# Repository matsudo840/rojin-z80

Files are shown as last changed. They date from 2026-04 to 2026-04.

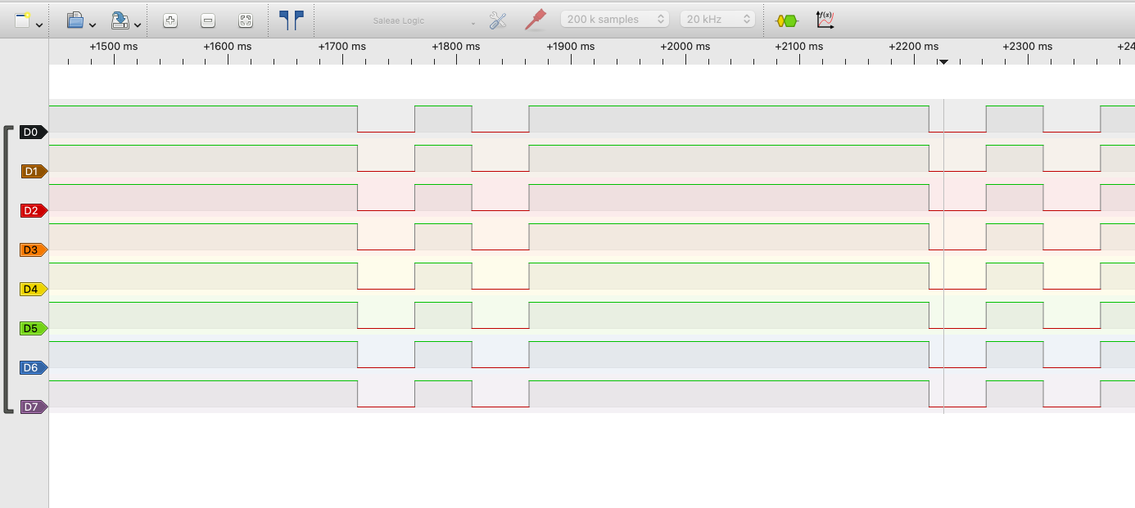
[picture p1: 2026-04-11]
images/step3_databus_waveform.png

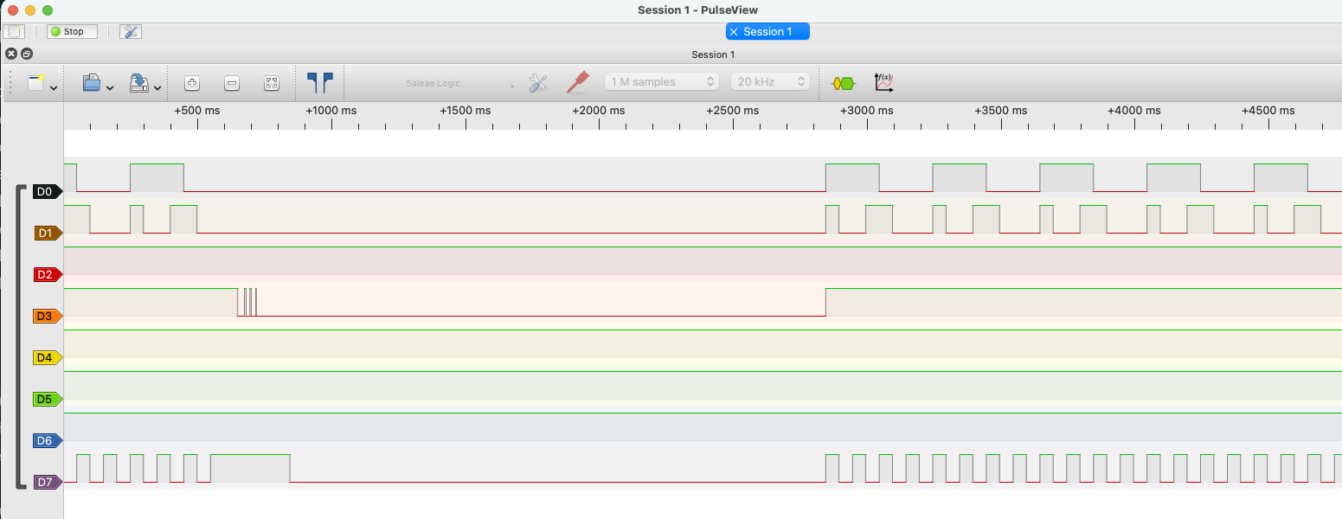
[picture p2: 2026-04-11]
images/z80_soft_reset_success.png

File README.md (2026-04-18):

# 老人Z80 - ESP32-S3によるZ80 CPU介護プロジェクト

このレポジトリは、[エムスリーテックブック9](https://techbookfest.org/product/tQtQhhFVHnRkH0bFCUikYK?productVariantID=5prWVthbVuZMdKxmcTBut0) 第9章「老人Z80 — ESP32によるZ80 CPU介護ボード製作記」のサポートページです。

本プロジェクトは、1970年代の名機Z80 CPUを、現代のパワフルなマイコン ESP32-S3 によって構築されたソフトウェア空間（仮想バス）上で動作させる、最新鋭の装置による旧来の存在の介護をテーマにした電子工作プロジェクトです。

## コンセプト
1991年のアニメ映画『老人Z』に登場する全自動看護ベッド「Z-001」から着想を得ました。
物理的なROMやRAM、周辺ICを一切排除し、ESP32-S3が「メモリ」「I/O」「クロック供給」「制御バスの調停」の役割をすべてソフトウェアで代行します。

- Z80から見た世界: 40年前と同じように周辺回路に囲まれている。
- 現実: ESP32-S3のソフトウェアが作り出す仮想バス空間上で、1サイクルごとに歩調を合わせられながら動作している。

## システム構成
- CPU: Zilog Z84C0008PEC (CMOS版 Z80)
- 介護マイコン: ESP32-S3 (ESP32-S3-DevKitC-1等)
- レベルシフタ: 74LVC245 (5V系Z80と3.3V系ESP32の電圧変換)
- 周辺機器: I2C 128x64 OLED (SSD1306)

### 介護（エミュレート）の内容
1. クロック供給: ESP32のGPIOから規則的なパルスを供給。
2. 仮想メモリ: ESP32のRAM上に確保した64KBの配列をZ80のメモリ空間として提供。
3. 同期制御: `/WAIT` 信号を用いて、ESP32側の処理（メモリ読み書きやOLED描画）が終わるまでZ80を一時停止。
4. I/Oブリッジ: Z80のI/Oリクエストを検知し、現代のI2C OLEDディスプレイへ文字出力。

## ディレクトリ構成
- `examples/`: 開発ステップごとのファームウェア・スナップショット。
- `firmware/`: ESP32-S3用のPlatformIOプロジェクト。
- `hardware/`: ピンアサイン、部品表(BOM)、回路図などのドキュメント。
- `images/`: 波形キャプチャや実行の様子。
- `tools/`: ロジックアナライザの波形（VCD形式）を解析するPythonスクリプト。

## 使い方
### ファームウェアの書き込み
`firmware/` ディレクトリをPlatformIO（VSCode拡張機能等）で開き、ESP32-S3に書き込みます。

### Z80アセンブラの実行
`firmware/src/main.cpp` 内の仮想メモリ配列に、Z80のアセンブラをバイナリ形式で配置することで実行可能です。

## 解析ツール
`tools/` 内のスクリプトを使用することで、ロジックアナライザで取得した波形データから、Z80がどのように命令をフェッチし、実行しているかを解析できます。

```bash
python tools/parse_vcd_fetch.py data.vcd
```

## ライセンス
MIT License

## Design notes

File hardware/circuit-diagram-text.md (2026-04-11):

# 老人Z80 回路図

## 1. システム全体ブロック図

```
┌─────────────────────────────────────────────────────────────┐
│                     電源供給系統                              │
├─────────────────────────────────────────────────────────────┤
│  USB 5V ──┬─→ Z80 (VCC)                                     │
│           ├─→ 74HC574 (VCC)                                 │
│           └─→ レベルシフタ A側 (5V入力)                      │
│                                                               │
│  ESP32 3.3V ─┬─→ レベルシフタ VCC (3.3V)                    │
│              └─→ レベルシフタ B側 (3.3V入力)                 │
│                                                               │
│  共通GND ────┴─ すべてのデバイスのGNDを接続                  │
└─────────────────────────────────────────────────────────────┘

┌──────────────┐
│   Z80 CPU    │  ← 老人（演算主体）
│  (5V駆動)    │
└──────────────┘
       │
       │ (神経接続: レベルシフタで電圧変換)
       │
       ↓
┌──────────────┐
│  LVC245 ×5   │  ← 神経系（5V ↔ 3.3V変換）
│ レベルシフタ  │
└──────────────┘
       │
       ↓
┌──────────────┐
│   ESP32-S3   │  ← 介護士（クロック供給、仮想メモリ、AI通信）
│  (3.3V駆動)  │
└──────────────┘
       │
       │ Wi-Fi
       ↓
   ChatGPT API
```

## 2. 詳細ピン接続図

### 2.1 アドレスバス (Z80 → ESP32) 一方向

```
┌─────────────┐          ┌─────────────┐          ┌─────────────┐
│   Z80       │          │  LVC245 #1  │          │  ESP32-S3   │
│             │          │  (Dir=Low)  │          │             │
│  A0  (pin30)├─────────→│ A1 → B1 ────┼─────────→│ GPIO 1      │
│  A1  (pin31)├─────────→│ A2 → B2 ────┼─────────→│ GPIO 2      │
│  A2  (pin32)├─────────→│ A3 → B3 ────┼─────────→│ GPIO 3      │
│  A3  (pin33)├─────────→│ A4 → B4 ────┼─────────→│ GPIO 4      │
│  A4  (pin34)├─────────→│ A5 → B5 ────┼─────────→│ GPIO 5      │
│  A5  (pin35)├─────────→│ A6 → B6 ────┼─────────→│ GPIO 6      │
│  A6  (pin36)├─────────→│ A7 → B7 ────┼─────────→│ GPIO 7      │
│  A7  (pin37)├─────────→│ A8 → B8 ────┼─────────→│ GPIO 8      │
└─────────────┘          └─────────────┘          └─────────────┘

┌─────────────┐          ┌─────────────┐          ┌─────────────┐
│   Z80       │          │  LVC245 #2  │          │  ESP32-S3   │
│             │          │  (Dir=Low)  │          │             │
│  A8  (pin38)├─────────→│ A1 → B1 ────┼─────────→│ GPIO 9      │
│  A9  (pin39)├─────────→│ A2 → B2 ────┼─────────→│ GPIO 10     │
│  A10 (pin40)├─────────→│ A3 → B3 ────┼─────────→│ GPIO 11     │
│  A11 (pin 1)├─────────→│ A4 → B4 ────┼─────────→│ GPIO 12     │
│  A12 (pin 2)├─────────→│ A5 → B5 ────┼─────────→│ GPIO 13     │
│  A13 (pin 3)├─────────→│ A6 → B6 ────┼─────────→│ GPIO 14     │
│  A14 (pin 4)├─────────→│ A7 → B7 ────┼─────────→│ GPIO 15     │
│  A15 (pin 5)├─────────→│ A8 → B8 ────┼─────────→│ GPIO 16     │
└─────────────┘          └─────────────┘          └─────────────┘
```

### 2.2 データバス (Z80 ↔ ESP32) 双方向

```
┌─────────────┐          ┌─────────────┐          ┌─────────────┐
│   Z80       │          │  LVC245 #3  │          │  ESP32-S3   │
│             │          │ (Dir制御)   │          │             │
│  D0  (pin14)├────────○─│ A1 ○ B1 ────┼────────○─│ GPIO 17     │
│  D1  (pin15)├────────○─│ A2 ○ B2 ────┼────────○─│ GPIO 18     │
│  D2  (pin12)├────────○─│ A3 ○ B3 ────┼────────○─│ GPIO 21     │
│  D3  (pin 8)├────────○─│ A4 ○ B4 ────┼────────○─│ GPIO 38     │
│  D4  (pin 7)├────────○─│ A5 ○ B5 ────┼────────○─│ GPIO 39     │
│  D5  (pin 9)├────────○─│ A6 ○ B6 ────┼────────○─│ GPIO 40     │
│  D6  (pin10)├────────○─│ A7 ○ B7 ────┼────────○─│ GPIO 41     │
│  D7  (pin13)├────────○─│ A8 ○ B8 ────┼────────○─│ GPIO 42     │
│             │          │             │          │             │
│             │          │ DIR (pin 1) │←─────────│ GPIO 19     │
└─────────────┘          └─────────────┘          └─────────────┘

※ GPIO 19 の制御:
  High: ESP32 → Z80 (データ書き込み)
  Low:  Z80 → ESP32 (データ読み込み)
```

### 2.3 制御信号

```
┌─────────────┐          ┌─────────────┐          ┌─────────────┐
│   Z80       │          │  LVC245 #4  │          │  ESP32-S3   │
│             │          │  (Dir制御)  │          │             │
│             │          │             │          │             │
│ CLK  (pin 6)│←─────────│ B1 ← A1 ────│←─────────│ GPIO 0      │
│WAIT (pin24) │←─────────│ B2 ← A2 ────│←─────────│ GPIO 45     │
│RESET(pin26) │←─────────│ B3 ← A3 ────│←─────────│ GPIO 46     │
│             │          │             │          │             │
└─────────────┘          └─────────────┘          └─────────────┘

┌─────────────┐          ┌─────────────┐          ┌─────────────┐
│   Z80       │          │  LVC245 #5  │          │  ESP32-S3   │
│             │          │  (Dir=Low)  │          │             │
│MREQ (pin19) ├─────────→│ A1 → B1 ────┼─────────→│ GPIO 47     │
│ RD  (pin21) ├─────────→│ A2 → B2 ────┼─────────→│ GPIO 48     │
└─────────────┘          └─────────────┘          └─────────────┘
```

### 2.4 出力系 (LED表示)

```
┌─────────────┐          ┌─────────────┐          ┌─────────────┐
│   Z80       │          │  74HC574    │          │   LED ×8    │
│             │          │  (ラッチ)   │          │             │
│  D0  (pin14)├─────────→│ D1 → Q1 ────┼─────────→│ LED 0       │
│  D1  (pin15)├─────────→│ D2 → Q2 ────┼─────────→│ LED 1       │
│  D2  (pin12)├─────────→│ D3 → Q3 ────┼─────────→│ LED 2       │
│  D3  (pin 8)├─────────→│ D4 → Q4 ────┼─────────→│ LED 3       │
│  D4  (pin 7)├─────────→│ D5 → Q5 ────┼─────────→│ LED 4       │
│  D5  (pin 9)├─────────→│ D6 → Q6 ────┼─────────→│ LED 5       │
│  D6  (pin10)├─────────→│ D7 → Q7 ────┼─────────→│ LED 6       │
│  D7  (pin13)├─────────→│ D8 → Q8 ────┼─────────→│ LED 7       │
│             │          │             │          │             │
│IORQ (pin20) ├──AND─────→│ CLK (pin11) │          │  (各LED直列に│
│  WR (pin22) ├──────┘    └─────────────┘          │   抵抗330Ω) │
└─────────────┘                                    └─────────────┘
```

## 3. 電源とGND配線

```
┌────────────────────────────────────────────────┐
│  5V系統 (USB)                                  │
├────────────────────────────────────────────────┤
│  ・Z80 VCC (pin 11)                            │
│  ・74HC574 VCC (pin 20)                        │
│  ・LVC245 #1～#5 A側入力 (5V)                  │
└────────────────────────────────────────────────┘

┌────────────────────────────────────────────────┐
│  3.3V系統 (ESP32から供給)                       │
├────────────────────────────────────────────────┤
│  ・LVC245 #1～#5 VCC (pin 20)                  │
│  ・LVC245 #1～#5 B側入力 (3.3V)                │
└────────────────────────────────────────────────┘

┌────────────────────────────────────────────────┐
│  共通GND                                        │
├────────────────────────────────────────────────┤
│  ・Z80 GND (pin 29)                            │
│  ・ESP32 GND (複数ピン)                         │
│  ・LVC245 #1～#5 GND (pin 10)                  │
│  ・74HC574 GND (pin 10)                        │
│  ・LED カソード (共通)                          │
│  ・USB GND                                     │
└────────────────────────────────────────────────┘
```

## 4. パスコン配置

```
各ICの電源ピン(VCC)とGND間に0.1μFセラミックコンデンサを配置:

・Z80: VCC(pin11) - GND(pin29)
・ESP32: 3V3ピン - GNDピン (複数箇所)
・LVC245 ×5: VCC(pin20) - GND(pin10) 各IC
・74HC574: VCC(pin20) - GND(pin10)
```

## 5. プルアップ抵抗配置

```
以下の信号線に10kΩプルアップ抵抗を5V電源に接続:

・Z80 データバス D0～D7 (8本)
・Z80 アドレスバス A0～A15 (16本)
・WAIT, RESET, MREQ, RD 信号
```

## 6. タイミングチャート（仮想メモリ読み出し）

```
CLK      ┐   ┌───┐   ┌───┐   ┌───
(GPIO 0) └───┘   └───┘   └───┘

MREQ     ────┐           ┌────────
(Z80→47)     └───────────┘

WAIT     ────┐       ┌────────────
(45→Z80)     └───────┘
             ↑       ↑
             │       └─ ESP32がデータ準備完了
             └───────── ESP32がZ80を停止

A0-A15   ────<アドレス確定>────────
(Z80→1-16)

D0-D7    ─────────<データ供給>────
(17-42)           ↑
                  └─ ESP32が仮想メモリから読み出したデータ

DIR      ────┐           ┌────────
(GPIO19)     └───────────┘
             High: ESP32→Z80
```

## 7. 部品配置の推奨レイアウト

```
[ブレッドボード 1枚目]
┌──────────────────────────┐
│   ESP32-S3 DevKit        │
│   (幅広: 40ピン程度)     │
└──────────────────────────┘

[ブレッドボード 2枚目]
┌──────────────────────────┐
│ LVC245 #1 (A0-A7)        │
│ LVC245 #2 (A8-A15)       │
│ LVC245 #3 (D0-D7)        │
└──────────────────────────┘

[ブレッドボード 3枚目]
┌──────────────────────────┐
│ Z80 CPU (DIPソケット)    │
│ LVC245 #4 (制御信号ESP→Z)│
│ LVC245 #5 (制御信号Z→ESP)│
│ 74HC574 + LED×8          │
└──────────────────────────┘
```

## 8. 配線色コーディング推奨

```
・5V電源: 赤
・3.3V電源: オレンジ
・GND: 黒
・アドレスバス: 黄色系
・データバス: 緑色系
・制御信号: 青色系
・クロック: 白
```

---

## 補足事項

### レベルシフタ方向制御
- LVC245 の DIR (pin 1) が High: A→B (5V→3.3V)
- LVC245 の DIR (pin 1) が Low: B→A (3.3V→5V)

### 注意点
1. すべてのレベルシフタのOE (pin 19) はGNDに接続（常時有効）
2. Z80のINT, NMI, BUSREQはプルアップして未使用
3. 74HC574のOE (pin 1) はGNDに接続（常時出力有効）

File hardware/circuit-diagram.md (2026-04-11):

# 老人Z80 回路図 (Mermaid版)

## 1. システム全体構成図

```mermaid
graph TB
    subgraph Power["電源供給系統"]
        USB[USB 5V電源]
        USB --> Z80_VCC[Z80 VCC]
        USB --> HC574_VCC[74HC574 VCC]
        USB --> LVC_A[レベルシフタ A側 5V]

        ESP_3V3[ESP32 3.3V出力]
        ESP_3V3 --> LVC_VCC[レベルシフタ VCC 3.3V]
        ESP_3V3 --> LVC_B[レベルシフタ B側 3.3V]

        GND[共通GND]
    end

    subgraph CPU["Z80 CPU (老人)"]
        Z80[Z84C0008<br/>8MHz CMOS<br/>5V駆動]
    end

    subgraph LevelShift["神経系 (電圧変換)"]
        LVC1[LVC245 #1<br/>A0-A7]
        LVC2[LVC245 #2<br/>A8-A15]
        LVC3[LVC245 #3<br/>D0-D7<br/>双方向]
        LVC4[LVC245 #4<br/>制御信号<br/>ESP→Z80]
        LVC5[LVC245 #5<br/>制御信号<br/>Z80→ESP]
    end

    subgraph MCU["ESP32 (介護士)"]
        ESP[ESP32-S3<br/>DevKitC-1<br/>N16R8<br/>3.3V駆動]
    end

    subgraph Output["出力系 (脈動)"]
        HC574[74HC574<br/>ラッチ]
        LED[LED×8<br/>バイタルサイン]
    end

    subgraph Cloud["AI (意識)"]
        ChatGPT[ChatGPT API<br/>プログラム生成]
    end

    Z80 -->|アドレスバス<br/>A0-A7| LVC1
    Z80 -->|アドレスバス<br/>A8-A15| LVC2
    Z80 <-->|データバス<br/>D0-D7| LVC3
    Z80 <-->|制御信号| LVC4
    Z80 -->|MREQ, RD| LVC5

    LVC1 -->|GPIO 1-8| ESP
    LVC2 -->|GPIO 9-16| ESP
    LVC3 <-->|GPIO 17-42| ESP
    LVC4 <-->|CLK(0), WAIT, RESET| ESP
    LVC5 -->|GPIO 47-48| ESP

    Z80 -->|データ出力| HC574
    HC574 --> LED

    ESP -->|Wi-Fi| ChatGPT

    style Z80 fill:#ff9999
    style ESP fill:#99ccff
    style LVC1 fill:#ffeb99
    style LVC2 fill:#ffeb99
    style LVC3 fill:#ffeb99
    style LVC4 fill:#ffeb99
    style LVC5 fill:#ffeb99
    style ChatGPT fill:#99ff99
```

## 2. データフロー詳細図

```mermaid
flowchart LR
    subgraph Z80_Side["Z80側 (5V)"]
        A_BUS[アドレスバス<br/>A0-A15<br/>16本]
        D_BUS[データバス<br/>D0-D7<br/>8本]
        CTRL_OUT[制御出力<br/>MREQ, RD]
        CTRL_IN[制御入力<br/>CLK, WAIT, RESET]
    end

    subgraph Converter["レベル変換 (5V ↔ 3.3V)"]
        LS_ADDR[LVC245 #1,#2<br/>Dir=Low<br/>一方向]
        LS_DATA[LVC245 #3<br/>Dir制御<br/>双方向]
        LS_OUT[LVC245 #5<br/>Dir=Low<br/>一方向]
        LS_IN[LVC245 #4<br/>Dir制御<br/>一方向]
    end

    subgraph ESP_Side["ESP32側 (3.3V)"]
        GPIO_ADDR[GPIO 1-16<br/>アドレス受信]
        GPIO_DATA[GPIO 17-42<br/>データ送受信]
        GPIO_MREQ[GPIO 47-48<br/>制御受信]
        GPIO_CTRL[GPIO 0,45,46<br/>制御送信]
        GPIO_DIR[GPIO 19<br/>方向制御]
    end

    A_BUS -->|5V| LS_ADDR
    LS_ADDR -->|3.3V| GPIO_ADDR

    D_BUS <-->|5V| LS_DATA
    LS_DATA <-->|3.3V| GPIO_DATA
    GPIO_DIR -.->|制御| LS_DATA

    CTRL_OUT -->|5V| LS_OUT
    LS_OUT -->|3.3V| GPIO_MREQ

    GPIO_CTRL -->|3.3V| LS_IN
    LS_IN -->|5V| CTRL_IN

    style A_BUS fill:#ffffcc
    style D_BUS fill:#ccffcc
    style CTRL_OUT fill:#ccccff
    style CTRL_IN fill:#ffccff
```

## 3. ピンアサイン詳細マップ

```mermaid
graph LR
    subgraph Z80_Pins["Z80 ピン配置"]
        direction TB
        A0_A7["A0-A7<br/>pin 30-37"]
        A8_A15["A8-A15<br/>pin 38-40, 1-5"]
        D0_D7["D0-D7<br/>pin 14,15,12,8,7,9,10,13"]
        CLK_PIN["CLK pin 6"]
        WAIT_PIN["WAIT pin 24"]
        RESET_PIN["RESET pin 26"]
        MREQ_PIN["MREQ pin 19"]
        RD_PIN["RD pin 21"]
    end

    subgraph LVC1_IC["LVC245 #1"]
        LVC1_A["A1-A8<br/>(5V側/Z80)"]
        LVC1_B["B1-B8<br/>(3.3V側/ESP)"]
        LVC1_A --> LVC1_B
    end

    subgraph LVC2_IC["LVC245 #2"]
        LVC2_A["A1-A8<br/>(5V側/Z80)"]
        LVC2_B["B1-B8<br/>(3.3V側/ESP)"]
        LVC2_A --> LVC2_B
    end

    subgraph LVC3_IC["LVC245 #3"]
        LVC3_A["A1-A8<br/>(5V側/Z80)"]
        LVC3_B["B1-B8<br/>(3.3V側/ESP)"]
        LVC3_DIR["DIR<br/>GPIO 19"]
        LVC3_B <--> LVC3_A
    end

    subgraph ESP_GPIO["ESP32 GPIO"]
        direction TB
        GPIO_1_8["GPIO 1-8"]
        GPIO_9_16["GPIO 9-16"]
        GPIO_17_42["GPIO 17,18,21,38-42"]
        GPIO_0["GPIO 0"]
        GPIO_45["GPIO 45"]
        GPIO_46["GPIO 46"]
        GPIO_47["GPIO 47"]
        GPIO_48["GPIO 48"]
        GPIO_19["GPIO 19"]
    end

    A0_A7 --> LVC1_A
    LVC1_B --> GPIO_1_8

    A8_A15 --> LVC2_A
    LVC2_B --> GPIO_9_16

    D0_D7 <--> LVC3_A
    LVC3_B <--> GPIO_17_42
    GPIO_19 --> LVC3_DIR

    GPIO_0 --> CLK_PIN
    GPIO_45 --> WAIT_PIN
    GPIO_46 --> RESET_PIN

    MREQ_PIN --> GPIO_47
    RD_PIN --> GPIO_48

    style A0_A7 fill:#ffe6cc
    style A8_A15 fill:#ffe6cc
    style D0_D7 fill:#ccffe6
    style CLK_PIN fill:#cce6ff
    style WAIT_PIN fill:#cce6ff
    style RESET_PIN fill:#cce6ff
```

## 4. 仮想メモリ動作シーケンス

```mermaid
sequenceDiagram
    participant Z80 as Z80 CPU
    participant CLK as CLK信号
    participant MREQ as MREQ信号
    participant WAIT as WAIT信号
    participant ESP as ESP32
    participant AI as ChatGPT

    Note over ESP,AI: 初期化: AIからプログラムを取得
    AI->>ESP: Z80マシン語コード送信
    ESP->>ESP: 仮想メモリに展開

    Note over Z80,ESP: 実行開始
    ESP->>CLK: クロックHigh
    activate Z80
    CLK->>Z80: 1クロック進行

    Z80->>MREQ: Low (メモリ要求)
    activate MREQ
    MREQ->>ESP: メモリアクセス検知

    ESP->>WAIT: Low (Z80を停止)
    activate WAIT
    WAIT->>Z80: 時間停止

    ESP->>ESP: アドレスバス読み取り<br/>(GPIO 1-16)
    ESP->>ESP: 仮想メモリから<br/>該当命令を取得

    ESP->>Z80: データバス経由で<br/>命令を供給<br/>(GPIO 17-42)

    ESP->>WAIT: High (停止解除)
    deactivate WAIT
    WAIT->>Z80: 時間再開

    deactivate MREQ
    Z80->>Z80: 命令実行
    deactivate Z80

    ESP->>CLK: クロックLow

    Note over Z80,ESP: 次のサイクルへ
```

## 5. タイミングチャート

```mermaid
%%{init: {'theme':'base'}}%%
gantt
    title Z80 仮想メモリ読み出しタイミング
    dateFormat X
    axisFormat %L

    section CLK (GPIO 0)
    High   :a1, 0, 100
    Low    :a2, 100, 100
    High   :a3, 200, 100

    section MREQ (Z80→47)
    High   :b1, 0, 50
    Low    :b2, 50, 150
    High   :b3, 200, 100

    section WAIT (45→Z80)
    High   :c1, 0, 60
    Low    :c2, 60, 100
    High   :c3, 160, 140

    section Address (Z80→1-16)
    Invalid:d1, 0, 50
    Valid  :crit, d2, 50, 150
    Invalid:d3, 200, 100

    section Data (17-42)
    HiZ    :e1, 0, 100
    Valid  :crit, e2, 100, 60
    HiZ    :e3, 160, 140

    section DIR (GPIO 19)
    Low    :f1, 0, 100
    High   :f2, 100, 60
    Low    :f3, 160, 140
```

## 6. 電源配線図

```mermaid
graph TD
    subgraph PowerSource["電源源"]
        USB[USB 5V]
        ESP_REG[ESP32 3.3V<br/>レギュレータ出力]
    end

    subgraph V5_Rail["5V電源レール"]
        Z80_V[Z80 VCC pin11]
        HC_V[74HC574 VCC pin20]
        LVC_A_V[LVC245 A側<br/>入力基準]
    end

    subgraph V3_Rail["3.3V電源レール"]
        LVC_VCC[LVC245 ×5<br/>VCC pin20]
        LVC_B_V[LVC245 B側<br/>入力基準]
    end

    subgraph GroundRail["共通GND"]
        Z80_G[Z80 GND pin29]
        ESP_G[ESP32 GND]
        LVC_G[LVC245 ×5<br/>GND pin10]
        HC_G[74HC574 GND pin10]
        LED_G[LED カソード]
        USB_G[USB GND]
    end

    subgraph Bypass["バイパスコンデンサ"]
        CAP_Z80[0.1μF<br/>Z80 VCC-GND]
        CAP_ESP[0.1μF ×複数<br/>ESP32]
        CAP_LVC[0.1μF ×5<br/>各LVC245]
        CAP_HC[0.1μF<br/>74HC574]
    end

    USB --> V5_Rail
    USB --> GroundRail
    ESP_REG --> V3_Rail
    ESP_REG --> GroundRail

    V5_Rail -.->|接続| CAP_Z80
    V5_Rail -.->|接続| CAP_HC
    V3_Rail -.->|接続| CAP_ESP
    V3_Rail -.->|接続| CAP_LVC

    CAP_Z80 -.-> GroundRail
    CAP_ESP -.-> GroundRail
    CAP_LVC -.-> GroundRail
    CAP_HC -.-> GroundRail

    style USB fill:#ff9999
    style ESP_REG fill:#99ccff
    style GroundRail fill:#333333,color:#ffffff
```

## 7. LED出力回路

```mermaid
graph LR
    subgraph Z80_Data["Z80 データバス"]
        D0[D0 pin14]
        D1[D1 pin15]
        D2[D2 pin12]
        D3[D3 pin8]
        D4[D4 pin7]
        D5[D5 pin9]
        D6[D6 pin10]
        D7[D7 pin13]
    end

    subgraph Control["制御信号"]
        IORQ[IORQ pin20]
        WR[WR pin22]
        AND[AND Gate]
        IORQ --> AND
        WR --> AND
    end

    subgraph Latch["74HC574 ラッチ"]
        direction TB
        IN[D1-D8入力]
        CLK_L[CLK pin11]
        OUT[Q1-Q8出力]
        IN --> OUT
    end

    subgraph LED_Array["LED表示"]
        LED0[LED0 + 330Ω]
        LED1[LED1 + 330Ω]
        LED2[LED2 + 330Ω]
        LED3[LED3 + 330Ω]
        LED4[LED4 + 330Ω]
        LED5[LED5 + 330Ω]
        LED6[LED6 + 330Ω]
        LED7[LED7 + 330Ω]
    end

    D0 --> IN
    D1 --> IN
    D2 --> IN
    D3 --> IN
    D4 --> IN
    D5 --> IN
    D6 --> IN
    D7 --> IN

    AND --> CLK_L

    OUT --> LED0
    OUT --> LED1
    OUT --> LED2
    OUT --> LED3
    OUT --> LED4
    OUT --> LED5
    OUT --> LED6
    OUT --> LED7

    LED0 --> GND[GND]
    LED1 --> GND
    LED2 --> GND
    LED3 --> GND
    LED4 --> GND
    LED5 --> GND
    LED6 --> GND
    LED7 --> GND

    style LED0 fill:#ffff99
    style LED1 fill:#ffff99
    style LED2 fill:#ffff99
    style LED3 fill:#ffff99
    style LED4 fill:#ffff99
    style LED5 fill:#ffff99
    style LED6 fill:#ffff99
    style LED7 fill:#ffff99
```

## 8. ブレッドボード配置図

```mermaid
graph TB
    subgraph BB1["ブレッドボード #1"]
        direction LR
        ESP32[ESP32-S3 DevKitC-1<br/>幅広40ピン構成<br/>両側に電源レール]
        POWER1[5V/3.3V/GND<br/>電源分配]
    end

    subgraph BB2["ブレッドボード #2"]
        direction LR
        LVC1[LVC245 #1<br/>A0-A7]
        LVC2[LVC245 #2<br/>A8-A15]
        LVC3[LVC245 #3<br/>D0-D7]
        LVC1 --- LVC2
        LVC2 --- LVC3
    end

    subgraph BB3["ブレッドボード #3"]
        direction LR
        Z80_IC[Z80 CPU<br/>DIP40ソケット]
        LVC4[LVC245 #4<br/>制御ESP→Z]
        LVC5[LVC245 #5<br/>制御Z→ESP]
        HC[74HC574<br/>+ LED×8]
        Z80_IC --- LVC4
        LVC4 --- LVC5
        LVC5 --- HC
    end

    BB1 -.->|フラットケーブル<br/>40本程度| BB2
    BB2 -.->|フラットケーブル<br/>20本程度| BB3

    style ESP32 fill:#99ccff
    style Z80_IC fill:#ff9999
    style LVC1 fill:#ffeb99
    style LVC2 fill:#ffeb99
    style LVC3 fill:#ffeb99
    style LVC4 fill:#ffeb99
    style LVC5 fill:#ffeb99
```

## 9. パスコン（バイパスコンデンサ）配置

各ICのVCC-GND間に0.1μFセラミックコンデンサを**できるだけ近く**に配置する。

| IC | 電源電圧 | パスコン容量 | 数量 | 配置位置 |
|----|---|---|---|---|
| Z80 CPU | 5V | 0.1μF | 1個 | pin11-pin29間 |
| 74HC574 | 5V | 0.1μF | 1個 | pin20-pin10間 |
| LVC245 #1 | 3.3V | 0.1μF | 1個 | pin20-pin10間 |
| LVC245 #2 | 3.3V | 0.1μF | 1個 | pin20-pin10間 |
| LVC245 #3 | 3.3V | 0.1μF | 1個 | pin20-pin10間 |
| LVC245 #4 | 3.3V | 0.1μF | 1個 | pin20-pin10間 |
| LVC245 #5 | 3.3V | 0.1μF | 1個 | pin20-pin10間 |
| ESP32-S3 | 3.3V | 0.1μF | 2-3個 | 各3.3V-GND間（複数箇所） |
| ESP32-S3 | 3.3V | 10μF | 1個 | 3.3V-GND間（バルク用） |

**合計必要数: 0.1μF × 9個、10μF × 1個**

## 10. 配線色コーディング

```mermaid
graph LR
    subgraph Colors["推奨配線色"]
        direction TB
        RED[赤: 5V電源]
        ORANGE[オレンジ: 3.3V電源]
        BLACK[黒: GND]
        YELLOW[黄色系: アドレスバス]
        GREEN[緑色系: データバス]
        BLUE[青色系: 制御信号]
        WHITE[白: クロック]
    end

    style RED fill:#ff0000,color:#ffffff
    style ORANGE fill:#ff9900,color:#000000
    style BLACK fill:#000000,color:#ffffff
    style YELLOW fill:#ffff00,color:#000000
    style GREEN fill:#00ff00,color:#000000
    style BLUE fill:#0099ff,color:#ffffff
    style WHITE fill:#ffffff,color:#000000
```

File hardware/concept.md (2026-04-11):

# 老人Z80 基本設計仕様書

## 1. コンセプト

1970年代の Z80 CPU を、ESP32-S3 と AI（ChatGPT）で包み込み、現代に蘇らせる「サイバー・レトロ」プロジェクト。

- **Z80 (Z84C0008)**: 本来は 5V 駆動だが、本プロジェクトでは 3.3V で駆動（しきい値ハック）。ESP32が提供する仮想メモリ上の命令を実行する。
- **ESP32-S3-DevKitC-1-N16R8**: 3.3V 駆動。Wi-Fi 経由で AI と通信し、Z80 用の仮想メモリとクロックを生成する。
- **レベルシフタ / バッファ (SN74LVC245AN)**: 当初は電圧変換 (5V ↔ 3.3V) を目的としていたが、現在は 3.3V 統一系における「バス・バッファ（保護およびドライブ能力向上）」として機能する。

---

## 2. ハードウェア構成

部品の詳細は [bom.md](bom.md) を参照。

---

## 3. 電源系統

### 5V系統
- **供給元**: USB電源
- **用途**:
  - Z80 (VCC pin 11)
  - 74HC574 (VCC pin 20)
  - レベルシフタのA側入力（5V基準）

### 3.3V系統
- **供給元**: ESP32の3.3V出力ピン
- **用途**:
  - レベルシフタ (VCC pin 20) - 全5個
  - レベルシフタのB側入力（3.3V基準）

### 共通GND
すべてのデバイスのGNDを一本化する。

---

## 4. ピンアサイン

> **重要**: 詳細なピン接続は [pin_map.md](pin_map.md) を正とします。

### 概要
- **アドレスバス (16本)**: GPIO 1～16
- **データバス (8本)**: GPIO 17, 18, 21, 38, 39, 40, 41, 42
- **制御信号**:
  - **CLK**: GPIO 0
  - **WAIT**: GPIO 45
  - **RESET**: GPIO 46
  - **MREQ**: GPIO 47
  - **RD**: GPIO 48
  - **DIR**: GPIO 19 (USB D-)

詳細なピン配置図は [circuit-diagram.md](circuit-diagram.md) を参照。

---

## 5. ソフトウェアロジック

### ① 仮想SRAMエミュレーション

1. ESP32が CLK をトグルし、Z80を1ステップ進める
2. Z80が MREQ をLowにしたら、ESP32は WAIT をLowにしてZ80を停止
3. ESP32がアドレスバスを読み取り、仮想メモリから該当する命令を取得
4. データバスに命令を出力し、WAIT を解除

### ② AI（ChatGPT）連携

1. Wi-Fi経由でOpenAI APIに接続
2. Z80用マシン語を生成させる
3. 受信したコードを仮想メモリに展開し、Z80に実行させる

### ③ デバッグ・モニタリング

- シリアル出力でバス状態を監視
- 実行トレースの記録
- リアルタイムでのメモリダンプ

---

## 6. 開発フェーズ

### Phase 1: 基本動作確認
- [ ] ブレッドボード配線
- [ ] 電源供給確認
- [ ] レベルシフタ動作確認
- [ ] クロック供給テスト
- [ ] LED点灯テスト

### Phase 2: 仮想メモリ実装
- [ ] ESP32でWAIT制御
- [ ] アドレスバス読み取り
- [ ] データバス書き込み
- [ ] 簡単なNOPループ実行
- [ ] 固定プログラムでのLチカ

### Phase 3: AI連携
- [ ] Wi-Fi接続
- [ ] ChatGPT API統合
- [ ] マシン語生成プロンプト最適化
- [ ] 自動実行パイプライン
- [ ] エラーハンドリング

### Phase 4: 拡張機能
- [ ] LED以外の出力デバイス
- [ ] 外部SRAM追加
- [ ] リアルタイムデバッガ
- [ ] Webインターフェース

---

## 7. 技術的課題

### 課題1: クロック速度のバランス
**問題**: ESP32の処理速度とZ80のクロック速度のバランス
**解決**: 可変クロック機能の実装。初期は低速（1kHz）から開始。

### 課題2: タイミング制約
**問題**: WAIT信号のタイミングが遅れるとZ80が誤動作
**解決**: GPIOの割り込みハンドラで最優先処理。アセンブリ最適化も検討。

### 課題3: メモリサイズ
**問題**: ESP32のメモリに64KBすべてを展開できない
**解決**: N16R8モデル（PSRAM 8MB）を使用。必要に応じてページング実装。

### 課題4: AI生成コードの検証
**問題**: ChatGPTが生成したマシン語が正しいとは限らない
**解決**: シミュレータでの事前検証機能を実装。

### 課題5: GPIOピンアサインの制約
詳細は [issues.md](issues.md) を参照。

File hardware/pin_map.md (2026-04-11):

# 老人Z80 GPIOピンアサイン定義書

このドキュメントは、本プロジェクトにおける ESP32-S3 と Z80 の接続ピン配置の **Single Source of Truth (唯一の正解)** です。
他のドキュメント (`concept.md`, `circuit-diagram.md`) と記述が食い違う場合は、**本書の記述を優先** します。

## 1. 方針と制約

1.  **USBポートの制限**: GPIOピン不足解消のため、`USB D-` (GPIO 19) を使用します。
    - **重要**: 開発および電源供給には **UARTポート** (USB-UARTブリッジ側) を使用してください。Native USBポートは使用できません。
2.  **RGB LED**: GPIO 48 (および一部のボードでは GPIO 38) は基板上の RGB LED (NeoPixel) に接続されています。これらは Z80 の制御信号（/RD 等）と競合するため、**起動時にソフトウェアで明示的に消灯** する必要があります。
3.  **Strapping Pins**: GPIO 0, 3, 45, 46 はブートモード決定ピンです。
    - ESP32の起動完了まで Z80 をリセット状態（ハイインピーダンス）に保つことで、ブート阻害を防ぎます。
14. **プルアップ構成**: 以下の信号線には、ノイズ対策およびフローティング防止のため、5Vへのプルアップ抵抗（例: $10 \text{k}\Omega$）を実装しています。
    - アドレスバス (A0-A15)
    - データバス (D0-D7)
    - 制御信号: INT, NMI, MREQ, IORQ, RD, WR, BUSACK, WAIT, BUSRQ, RESET, M1 (HALT, RFSHを除く主要信号)

## 2. ピンアサイン一覧

### A. アドレスバス (Z80 输出 → ESP32 入力)
| 信号名 | Z80 Pin | ESP32 GPIO | 備考 |
|:---|:---:|:---:|:---|
| **A0** | 30 | **GPIO 1** | |
| **A1** | 31 | **GPIO 2** | |
| **A2** | 32 | **GPIO 3** | Strap Pin (JTAG) |
| **A3** | 33 | **GPIO 4** | |
| **A4** | 34 | **GPIO 5** | |
| **A5** | 35 | **GPIO 6** | |
| **A6** | 36 | **GPIO 7** | |
| **A7** | 37 | **GPIO 8** | |
| **A8** | 38 | **GPIO 9** | |
| **A9** | 39 | **GPIO 10** | |
| **A10** | 40 | **GPIO 11** | |
| **A11** | 1 | **GPIO 12** | |
| **A12** | 2 | **GPIO 13** | |
| **A13** | 3 | **GPIO 0** | (← 14 から変更) Boot Button / Strap Pin |
| **A14** | 4 | **(N/C)** | GPIO不足のため廃止 |
| **A15** | 5 | **(N/C)** | GPIO不足のため廃止 |

### B. データバス (Z80 ⇔ ESP32 双方向)
| 信号名 | Z80 Pin | ESP32 GPIO | 備考 |
|:---|:---:|:---:|:---|
| **D0** | 14 | **GPIO 17** | |
| **D1** | 15 | **GPIO 18** | |
| **D2** | 12 | **GPIO 21** | |
| **D3** | 8 | **GPIO 38** | RGB LEDと競合の可能性あり |
| **D4** | 7 | **GPIO 39** | JTAG |
| **D5** | 9 | **GPIO 40** | JTAG |
| **D6** | 10 | **GPIO 41** | JTAG |
| **D7** | 13 | **GPIO 42** | JTAG |

### C. 制御信号
| 信号名 | 方向 | ESP32 GPIO | 役割・備考 |
|:---|:---:|:---:|:---|
| **CLK** | ESP→Z80 | **GPIO 14** | (← 0 から変更) コンデンサ回避のためクリーンなピンへ移動 |
| **WAIT** | ESP→Z80 | **GPIO 45** | Strap (Output) |
| **RESET** | ESP→Z80 | **GPIO 46** | Strap (Output) |
| **MREQ** | Z80→ESP | **GPIO 47** | Input |
| **RD** | Z80→ESP | **GPIO 48** | Input / **オンボードNeoPixelと共用 (要消灯)** |
| **WR** | Z80→ESP | **GPIO 16** | Input (A15から転用) |
| **IORQ** | Z80→ESP | **GPIO 35** | Input |
| **DIR** | ESP→LVC | **GPIO 15** | (A14から転用) |
| **SDA** | ESP⇔OLED | **GPIO 36** | I2C Data |
| **SCL** | ESP→OLED | **GPIO 37** | I2C Clock |

---

## 3. レベルシフタ (74LVC245) 構成

- **LVC #1**: A0-A7 (Direction: High 固定 / Z80→ESP)
- **LVC #2**: A8-A13 (Direction: High 固定 / Z80→ESP)
- **LVC #3**: D0-D7 (Direction: **GPIO 15** で制御)
    - Low: ESP → Z80 (Write to Z80)
    - High: Z80 → ESP (Read from Z80)
- **LVC #4**: CLK, WAIT, RESET (Direction: Low 固定 / ESP→Z80)
    - **注意**: LVC245の配線方向を **A=Z80 (5V), B=ESP (3.3V)** とします。
- **LVC #5**: , IORQ (Direction: High 固定 / Z80→ESP)
    - WR: Z80 Pin 22 -> LVC #5 -> **GPIO 16**
    - RD: Z80 Pin 21 -> LVC #5 -> **GPIO 48**
    - MREQ: Z80 Pin 19 -> LVC #5 -> **GPIO 47**
    - IORQ: Z80 Pin 20 -> LVC #5 -> **GPIO 35**

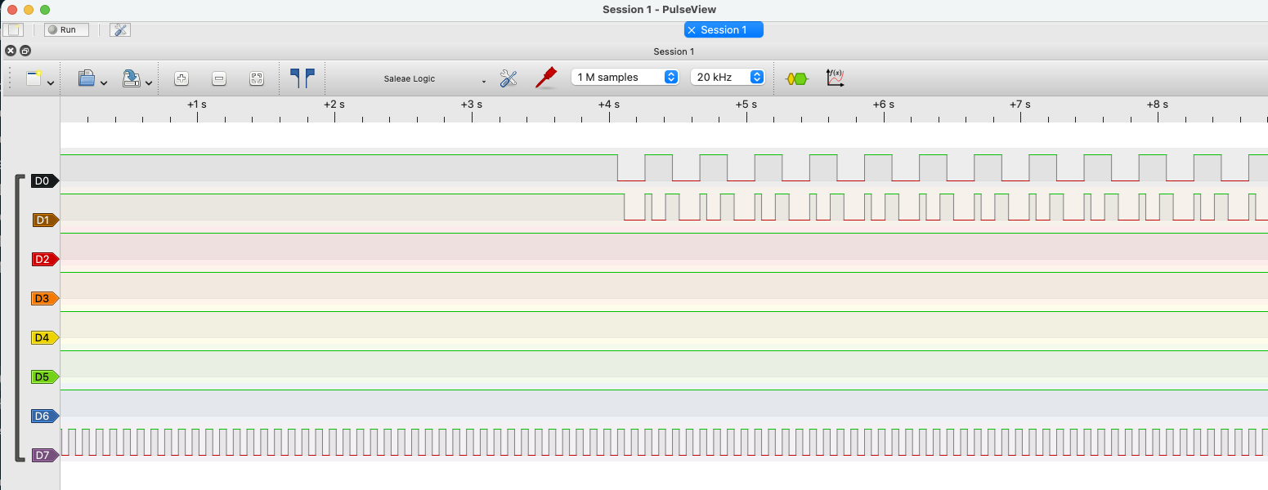
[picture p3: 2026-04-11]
images/z80_nop_fetch_signature.png

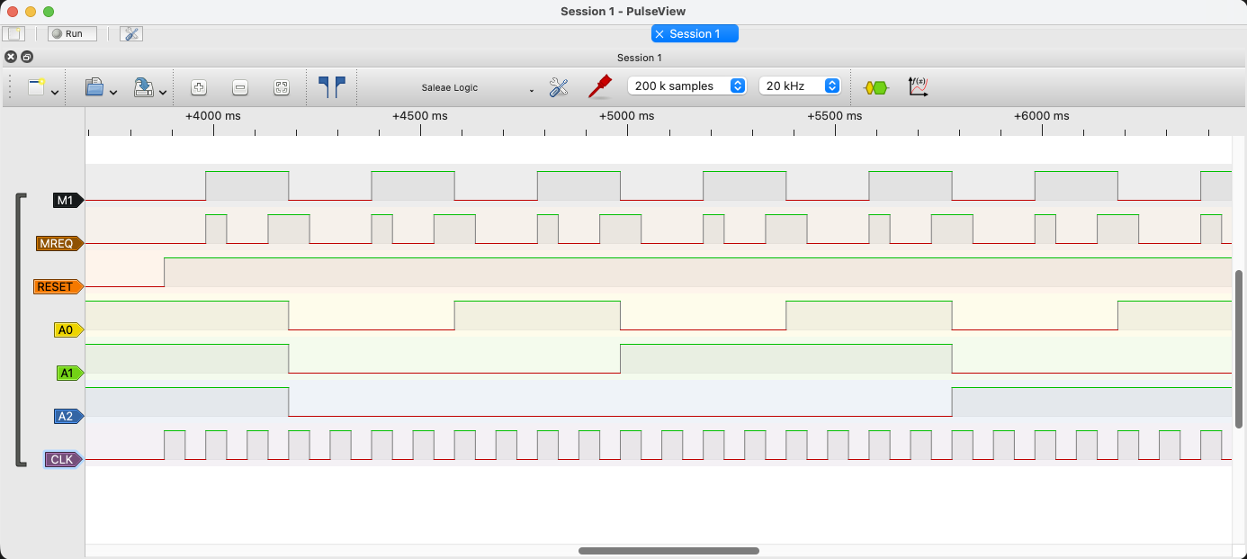
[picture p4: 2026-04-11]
images/z80_freerun_success.png

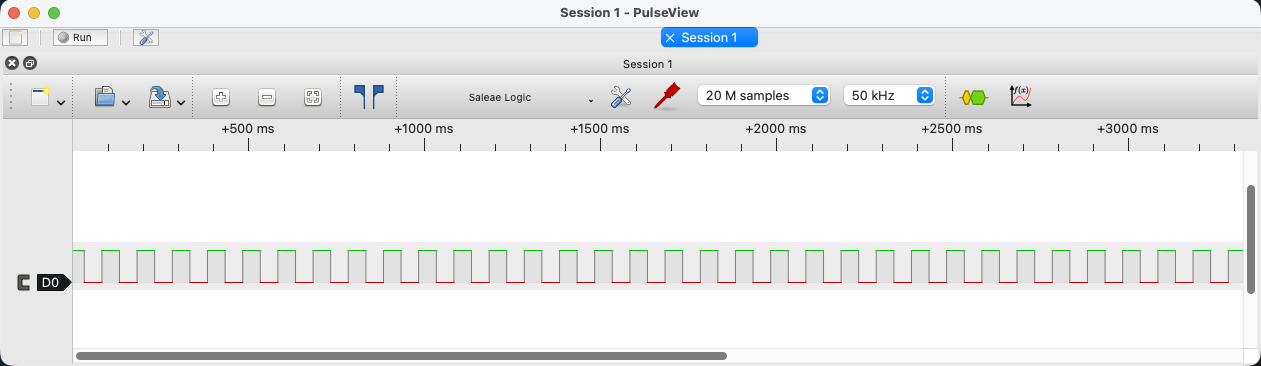
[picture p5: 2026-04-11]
images/clk_10hz_logic_capture.png

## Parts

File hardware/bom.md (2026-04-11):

# 老人Z80 部品表 (BOM)

## 必須部品

| カテゴリ | 部品名/型番 | 数量 | 単価目安 | 購入先 | 備考 |
|---|---|---|---|---|---|
| **CPU** | Z84C0008PEG (CMOS 8MHz) | 1 | ¥500-800 | 秋月電子、千石電商 | DIP40パッケージ |
| **MCU** | ESP32-S3-DevKitC-1-N16R8 | 1 | ¥2,500-3,000 | スイッチサイエンス、秋月 | 16MB Flash + 8MB PSRAM |
| **レベルシフタ** | SN74LVC245AN (DIP20) | 5 | ¥100-150/個 | 秋月電子、千石電商 | 双方向、3.3V ↔ 5V |
| **ラッチIC** | 74HC574 (DIP20) | 1 | ¥50-80 | 秋月電子、千石電商 | 8bitラッチ、LED駆動用 |
| **LED** | 赤色LED 3mm または 5mm | 8 | ¥10-20/個 | 秋月電子 | 順方向電圧1.8-2.2V |
| **抵抗** | 330Ω 1/4W カーボン抵抗 | 8 | ¥5/個 | 秋月電子 | LED電流制限用 |
| **抵抗** | 10kΩ 集合抵抗 9ピンコモン | 5 | ¥100-150/個 | 秋月電子 | バスプルアップ用 |
| **コンデンサ** | 積層セラミック 0.1μF 50V | 20 | ¥10-20/個 | 秋月電子 | パスコン（各IC用） |
| **ブレッドボード** | 大型ブレッドボード (830穴) | 3 | ¥400-600/枚 | 秋月電子 | 連結式推奨 |
| **ジャンパワイヤ** | オス-オス ジャンパワイヤセット | 1セット | ¥500-1,000 | 秋月電子 | 各色100本程度 |
| **ICソケット** | DIP40ピン ICソケット | 1 | ¥80-150 | 秋月電子 | Z80用（抜き差し容易） |
| **ICソケット** | DIP20ピン ICソケット | 6 | ¥30-50/個 | 秋月電子 | レベルシフタ、ラッチ用 |
| **電源** | USB ACアダプタ 5V 2A | 1 | ¥500-800 | 秋月電子、100円ショップ | ESP32とZ80の電源 |
| **ケーブル** | USBケーブル Micro-B or Type-C | 1 | ¥300-500 | 秋月電子 | ESP32接続用 |

## オプション部品

| カテゴリ | 部品名/型番 | 数量 | 単価目安 | 用途 |
|---|---|---|---|---|
| **SRAM** | AS6C62256 (32KB SRAM) | 1 | ¥300-500 | 外部メモリ拡張 |
| **オシロスコープ** | DSO138 など | 1 | ¥3,000-5,000 | 信号波形確認 |
| **ロジックアナライザ** | Saleae互換品 | 1 | ¥1,000-3,000 | バス信号解析 |
| **ケース** | アクリルケース | 1 | ¥1,000-2,000 | 完成後の保護 |

## 工具

| 工具名 | 必要性 | 備考 |
|---|---|---|
| ニッパー | 必須 | ジャンパワイヤカット |
| ワイヤーストリッパー | 推奨 | 被覆剥き |
| ピンセット | 推奨 | 小型部品配置 |
| テスター（マルチメータ） | 必須 | 電圧・導通確認 |
| ハンダゴテ | オプション | ヘッダピン取り付け等 |

## 合計概算費用

| 項目 | 金額 |
|---|---|
| 必須部品 | 約 ¥8,000 - ¥12,000 |
| オプション部品 | 約 ¥5,000 - ¥10,000 |
| 工具（初めて揃える場合） | 約 ¥3,000 - ¥5,000 |
| **総計** | **約 ¥11,000 - ¥22,000** |

## 購入時の注意点

### Z80 CPU
- **CMOS版 (Z84C00xxPEG)** を推奨（消費電力が低く、5V単一電源）
- NMOS版 (Z80A) は+5V, -5V, +12Vの3電源が必要なため非推奨
- クロック速度は4MHz、6MHz、8MHzがあるが、8MHz推奨

### ESP32
- **ESP32-S3** を推奨（PSRAMでプログラムバッファ確保）
- ESP32-DevKitC（無印）でも動作可能だが、メモリが少ない
- GPIO数が多いモデルを選ぶこと

### レベルシフタ
- **SN74LVC245AN** または **SN74LVC245A** (DIPパッケージ必須)
- 74HC245 は使用不可（3.3V動作不可）
- TXS0108E等の自動方向検知タイプは避ける（速度面で不利）

### ブレッドボード
- ESP32-S3 DevKitC-1は幅が広いため、**両側に電源レールがあるタイプ**推奨
- 連結できるタイプが配線しやすい
- 安定性のため、金属ベース付きを推奨

## 購入リンク例（2024年時点）

### 秋月電子通商
- Z80 CPU: https://akizukidenshi.com/
- レベルシフタ: https://akizukidenshi.com/
- ブレッドボード: https://akizukidenshi.com/

### スイッチサイエンス
- ESP32-S3 DevKitC-1: https://www.switch-science.com/

### 千石電商
- 各種IC、部品: https://www.sengoku.co.jp/

## 在庫確認

部品の在庫状況は変動しやすいため、購入前に必ず在庫を確認してください。
特にZ80 CPUやレベルシフタICは入手困難になることがあります。

---

更新日: 2025-01-XX

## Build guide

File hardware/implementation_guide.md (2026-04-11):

# Rojin Z80 実装ガイド

技術記事 (Note/Zenn等) の執筆を目的とした、**PoC (Proof of Concept) 主導型開発** のための公式ガイドラインです。
本プロジェクトでは、プリント基板 (PCB) の作成は行わず、ブレッドボード上での実証実験を最終成果物とします。

## 1. 開発ロードマップ (Iterative Process)

全体を一度に構築するのではなく、以下のフェーズに分割して開発を進めます。各フェーズの成果が、そのまま技術記事の各章となります。

### Phase 1: The Heartbeat (クロック生成)
Z80を駆動するためのクロック信号をESP32から供給する仕組みを構築します。
- **目標**: ESP32単体で矩形波を生成し、安定性（ジッターや周波数精度）を検証する。
- **検証方法**: LED点滅による目視確認、またはロジックアナライザによる波形観測（オシロスコープは不要）。

### Phase 2: The Awakening (フリーラン)
Z80に電源とクロックを供給し、命令フェッチサイクルが機能することを確認します。
- **目標**: データバスに `NOP (0x00)` を固定入力し、Z80のアドレスバスが `0x0000` から `0xFFFF` まで順次カウントアップする様子を観測する。
- **実装**: ブレッドボード上でのESP32、レベルシフタ、Z80の物理配線。

### Phase 3: The Conversation (メモリ・エミュレーション)
ESP32を仮想メモリとして機能させ、Z80からのバスアクセスに応答するシステムを構築します。
- **目標**: Z80が発行したメモリアドレスをESP32が読み取り、対応する命令コードをデータバスに出力する。
- **実装**:
    - アドレスバス読み取りロジック（GPIO入力）
    - データバス書き込みロジック（GPIO出力、双方向制御）
    - バス調停（WAIT信号によるタイミング制御）

### Phase 4: The Consciousness (AI連携)
「意識」としてのAI (ChatGPT) と統合し、動的に生成されたコードを実行させます。
- **目標**: Wi-Fi経由で取得したZ80マシン語を、仮想メモリ領域に展開し実行する。

---

## 2. 開発環境・ツールセット

### A. 回路設計・配線図
**推奨ツール: [Fritzing](https://fritzing.org/)**
- **選定理由**: 記事読者への可読性を最優先し、実体配線図（ブレッドボード図）の作成に適したツールを採用します。

### B. ファームウェア (ESP32 Firmware)
本プロジェクトにおける「ファームウェア」とは、ESP32-S3上で動作する制御プログラムを指します。
ESP32は単なる周辺機器ではなく、システム全体の **「ホストコントローラ兼メモリデバイス」** として機能します。

- **主な役割**:
    1.  **システムクロック供給**: Z80へのクロック信号生成。
    2.  **バス・エミュレーション**: Z80のバスサイクル（MREQ, RD, WRなど）を監視し、メモリやI/Oとして振る舞う。
    3.  **ネットワーク通信**: Wi-Fi接続およびOpenAI APIとの通信。
- **開発環境**: **VS Code + PlatformIO**
    - 複雑なマルチタスク処理（Wi-Fi通信とマイクロ秒単位のバス制御の並立）が必要となるため、高度なデバッグ機能とライブラリ管理を持つPlatformIOを標準環境とします。

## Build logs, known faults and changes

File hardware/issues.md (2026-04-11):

# 老人Z80 未解決の技術課題

本ドキュメントでは、現在直面している技術的な課題のみを扱います。
解決済みの課題（GPIOピンアサインの競合など）については、[pin_map.md](pin_map.md) や [implementation_guide.md](implementation_guide.md) の履歴を参照してください。

## 1. ソフトウェア実装の課題 (未着手)

### 1.1 クロック生成の安定性
- **課題**: ESP32から安定したクロックを供給しつつ、Wi-Fi通信を維持できるか。
- **対応予定**: Step 1 のPoCで検証する。

### 1.2 高速バスアクセス
- **課題**: Z80のメモリアクセス要求に対して、ESP32が十分に高速に応答できるか。
- **対応予定**: Step 2, 3 のPoCで検証し、必要であればアセンブリ言語での最適化を行う。

---

## 参考リンク
- [ESP32-S3-DevKitC-1 v1.1 公式ユーザーガイド](https://docs.espressif.com/projects/esp-dev-kits/en/latest/esp32s3/esp32-s3-devkitc-1/user_guide_v1.1.html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)

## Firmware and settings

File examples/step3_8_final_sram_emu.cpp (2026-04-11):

#include <Arduino.h>
#include <Adafruit_NeoPixel.h>

// For ESP32-S3 direct GPIO register access
#include "hal/gpio_ll.h"
#include "soc/gpio_struct.h"

// --- Pin Definitions (Single Source of Truth: pin_map.md) ---
const int ADDR_PINS[] = {1, 2, 3, 4, 5, 6, 7, 8, 9, 10, 11, 12, 13, 14, 15, 16};
const int DATA_PINS[] = {17, 18, 21, 38, 39, 40, 41, 42};
const int CLK_PIN = 0;
const int DIR_PIN = 19;
const int WAIT_PIN = 45;
const int RESET_PIN = 46;
const int MREQ_PIN = 47;
const int RD_PIN = 48;
const int WR_PIN = 20;

// --- Virtual Memory (64KB) ---
uint8_t virtual_memory[0x10000];

Adafruit_NeoPixel pixels(1, 48, NEO_GRB + NEO_KHZ800);

// --- Optimized Bus Helper Functions ---

uint8_t current_bus_mode = 255;

void setDataBusMode(uint8_t mode) {
  if (current_bus_mode == mode)
    return;
  current_bus_mode = mode;

  if (mode == OUTPUT) {
    digitalWrite(DIR_PIN, LOW); // ESP -> Z80 (LVC DIR: Low)
    for (int pin : DATA_PINS) pinMode(pin, OUTPUT);
  } else {
    for (int pin : DATA_PINS) pinMode(pin, INPUT);
    digitalWrite(DIR_PIN, HIGH); // Z80 -> ESP (LVC DIR: High)
  }
}

inline uint16_t getAddressFast() {
  // Map GPIO 1-16 to A0-A15
  return (uint16_t)((GPIO.in >> 1) & 0xFFFF);
}

inline uint8_t readDataBusFast() {
  uint32_t gpio_0_31 = GPIO.in;
  uint32_t gpio_32_63 = GPIO.in1.val;

  uint8_t data = 0;
  if (gpio_0_31 & (1 << 17)) data |= (1 << 0);
  if (gpio_0_31 & (1 << 18)) data |= (1 << 1);
  if (gpio_0_31 & (1 << 21)) data |= (1 << 2);
  if (gpio_32_63 & (1 << (38 - 32))) data |= (1 << 3);
  if (gpio_32_63 & (1 << (39 - 32))) data |= (1 << 4);
  if (gpio_32_63 & (1 << (40 - 32))) data |= (1 << 5);
  if (gpio_32_63 & (1 << (41 - 32))) data |= (1 << 6);
  if (gpio_32_63 & (1 << (42 - 32))) data |= (1 << 7);
  return data;
}

inline void writeDataBusFast(uint8_t data) {
  uint32_t set_0_31 = 0, set_32_63 = 0;
  uint32_t clr_0_31 = 0, clr_32_63 = 0;

  (data & 0x01) ? set_0_31 |= (1 << 17) : clr_0_31 |= (1 << 17);
  (data & 0x02) ? set_0_31 |= (1 << 18) : clr_0_31 |= (1 << 18);
  (data & 0x04) ? set_0_31 |= (1 << 21) : clr_0_31 |= (1 << 21);
  (data & 0x08) ? set_32_63 |= (1 << (38 - 32)) : clr_32_63 |= (1 << (38 - 32));
  (data & 0x10) ? set_32_63 |= (1 << (39 - 32)) : clr_32_63 |= (1 << (39 - 32));
  (data & 0x20) ? set_32_63 |= (1 << (40 - 32)) : clr_32_63 |= (1 << (40 - 32));
  (data & 0x40) ? set_32_63 |= (1 << (41 - 32)) : clr_32_63 |= (1 << (41 - 32));
  (data & 0x80) ? set_32_63 |= (1 << (42 - 32)) : clr_32_63 |= (1 << (42 - 32));

  GPIO.out_w1ts = set_0_31;
  GPIO.out_w1tc = clr_0_31;
  GPIO.out1_w1ts.val = set_32_63;
  GPIO.out1_w1tc.val = clr_32_63;
}

void setup() {
  Serial.begin(115200);
  
  // Turn off bright NeoPixel
  pixels.begin();
  pixels.setPixelColor(0, pixels.Color(0, 0, 0));
  pixels.show();

  // Initialize Memory with a simple program:
  memset(virtual_memory, 0, sizeof(virtual_memory));
  virtual_memory[0x0000] = 0x3E; // LD A, 0x55
  virtual_memory[0x0001] = 0x55;
  virtual_memory[0x0002] = 0x00; // NOP
  virtual_memory[0x0003] = 0xC3; // JP 0x0000
  virtual_memory[0x0004] = 0x00;
  virtual_memory[0x0005] = 0x00;

  // Pin Modes
  pinMode(CLK_PIN, OUTPUT);
  pinMode(DIR_PIN, OUTPUT);
  pinMode(WAIT_PIN, OUTPUT);
  pinMode(RESET_PIN, OUTPUT);
  pinMode(MREQ_PIN, INPUT);
  pinMode(RD_PIN, INPUT);
  pinMode(WR_PIN, INPUT);

  for (int pin : ADDR_PINS) pinMode(pin, INPUT);
  setDataBusMode(OUTPUT);

  // RESET Sequence
  digitalWrite(WAIT_PIN, HIGH);
  digitalWrite(RESET_PIN, LOW);
  for (int i = 0; i < 40; i++) {
    digitalWrite(CLK_PIN, HIGH); delay(1);
    digitalWrite(CLK_PIN, LOW); delay(1);
  }
  digitalWrite(RESET_PIN, HIGH);
  Serial.println("Z80 Started (SRAM Emulation - WAIT Sync Mode)");
}

unsigned long last_clk_time = 0;
bool clk_high = false;

inline void updateClockFast() {
  unsigned long now = millis();
  if (now - last_clk_time >= 50) { // 10Hz
    clk_high = !clk_high;
    if (clk_high) GPIO.out_w1ts = (1 << 0);
    else GPIO.out_w1tc = (1 << 0);
    last_clk_time = now;
  }
}

void loop() {
  updateClockFast();

  uint32_t gpio_32_63 = GPIO.in1.val;

  // Check if MREQ (GPIO 47) is LOW
  if (!(gpio_32_63 & (1 << (47 - 32)))) {
    
    // MREQ is LOW! Immediately assert WAIT (LOW) to freeze Z80
    GPIO.out1_w1tc.val = (1 << (45 - 32));

    // Wait for RD or WR
    bool is_rd = false, is_wr = false;
    while (true) {
      uint32_t val_32_63 = GPIO.in1.val;
      uint32_t val_0_31 = GPIO.in;
      is_rd = !(val_32_63 & (1 << (48 - 32)));
      is_wr = !(val_0_31 & (1 << 20));
      if (is_rd || is_wr) break;
      updateClockFast();
    }

    uint16_t addr = getAddressFast();

    if (is_rd) {
      uint8_t data = virtual_memory[addr];
      setDataBusMode(OUTPUT);
      writeDataBusFast(data);
      Serial.printf("RD %04X: %02X
", addr, data);
      
      GPIO.out1_w1ts.val = (1 << (45 - 32)); // Release WAIT
      while (!(GPIO.in1.val & (1 << (47 - 32)))) updateClockFast();
      setDataBusMode(INPUT);
    } else {
      setDataBusMode(INPUT);
      uint8_t data = readDataBusFast();
      virtual_memory[addr] = data;
      Serial.printf("WR %04X: %02X
", addr, data);

      GPIO.out1_w1ts.val = (1 << (45 - 32)); // Release WAIT
      while (!(GPIO.in1.val & (1 << (47 - 32)))) updateClockFast();
    }
  }
}

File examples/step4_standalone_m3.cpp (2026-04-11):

#include <Arduino.h>
#include <Adafruit_GFX.h>
#include <Adafruit_SSD1306.h>
#include <Adafruit_NeoPixel.h>
#include <Wire.h>

/* 
 * Roujin Z80: Final Production Edition
 * - Identical timing to the "Perfectly Working" version.
 * - Standalone stable: No serial hangs, no LED interference.
 */

const uint8_t ADDR_PINS[] = {1, 2, 3, 4, 5, 6, 7, 8, 9, 10, 11, 12, 13, 0}; 
const uint8_t DATA_PINS[] = {17, 18, 21, 38, 39, 40, 41, 42};

#define CLK_PIN    14
#define WAIT_PIN   45
#define RESET_PIN  46
#define MREQ_PIN   47
#define RD_PIN     48
#define WR_PIN     16
#define IORQ_PIN   35
#define DIR_PIN    15

#define OLED_SDA   36
#define OLED_SCL   37
#define SCREEN_WIDTH 128
#define SCREEN_HEIGHT 64
#define SCREEN_ADDRESS 0x3C

Adafruit_SSD1306 display(SCREEN_WIDTH, SCREEN_HEIGHT, &Wire, -1);

Adafruit_NeoPixel led48(1, 48, NEO_GRB + NEO_KHZ800);
Adafruit_NeoPixel led38(1, 38, NEO_GRB + NEO_KHZ800);

uint8_t virtual_memory[0x4000]; // 16KB

const uint8_t z80_program[] = {
    0x3E, 0x4D,       // 0000: LD A, 'M'
    0xD3, 0x80,       // 0002: OUT (0x80), A
    0x3E, 0x33,       // 0004: LD A, '3'
    0xD3, 0x80,       // 0006: OUT (0x80), A
    0x3E, 0x21,       // 0008: LD A, '!'
    0xD3, 0x80,       // 000A: OUT (0x80), A
    0x3E, 0x20,       // 000C: LD A, ' '
    0xD3, 0x80,       // 000E: OUT (0x80), A
    0xC3, 0x00, 0x00  // 0010: JP 0000
};

inline uint16_t getAddress() {
    uint32_t gpio_in = GPIO.in;
    return ((gpio_in >> 1) & 0x1FFF) | ((gpio_in & 0x01) << 13);
}

void setDataBusMode(uint8_t mode) {
    if (mode == OUTPUT) {
        digitalWrite(DIR_PIN, LOW); 
        delayMicroseconds(1);
        for (int i = 0; i < 8; i++) pinMode(DATA_PINS[i], OUTPUT);
    } else {
        for (int i = 0; i < 8; i++) pinMode(DATA_PINS[i], INPUT);
        delayMicroseconds(1);
        digitalWrite(DIR_PIN, HIGH);
    }
}

inline uint8_t getData() {
    uint8_t data = 0;
    for (int i = 0; i < 8; i++) {
        if (digitalRead(DATA_PINS[i])) data |= (1 << i);
    }
    return data;
}

inline void setData(uint8_t data) {
    for (int i = 0; i < 8; i++) {
        digitalWrite(DATA_PINS[i], (data >> i) & 0x01);
    }
}

void pulseClock() {
    digitalWrite(CLK_PIN, HIGH);
    delayMicroseconds(10);
    digitalWrite(CLK_PIN, LOW);
    delayMicroseconds(10);
}

void setup() {
    // Keep Serial active but don't print to avoid buffer issues
    Serial.begin(115200);

    // Disable LEDs
    led48.begin(); led48.setPixelColor(0, 0); led48.show();
    led38.begin(); led38.setPixelColor(0, 0); led38.show();
    
    pinMode(RESET_PIN, OUTPUT);
    digitalWrite(RESET_PIN, LOW);
    
    pinMode(CLK_PIN, OUTPUT);
    pinMode(WAIT_PIN, OUTPUT);
    pinMode(MREQ_PIN, INPUT);
    pinMode(RD_PIN, INPUT);
    pinMode(WR_PIN, INPUT);
    pinMode(IORQ_PIN, INPUT);
    pinMode(DIR_PIN, OUTPUT);

    digitalWrite(WAIT_PIN, HIGH);
    for (int i = 0; i < 14; i++) pinMode(ADDR_PINS[i], INPUT);
    setDataBusMode(INPUT);

    Wire.begin(OLED_SDA, OLED_SCL);
    display.begin(SSD1306_SWITCHCAPVCC, SCREEN_ADDRESS);
    display.clearDisplay();
    display.setTextSize(2);
    display.setTextColor(SSD1306_WHITE);
    
    display.setCursor(0,0);
    display.println(F("Roujin Z80"));
    display.setCursor(0, 16);
    display.display();

    memset(virtual_memory, 0, sizeof(virtual_memory));
    memcpy(virtual_memory, z80_program, sizeof(z80_program));

    // Wait for power to stabilize
    delay(500);

    for(int i = 0; i < 100; i++) { pulseClock(); }
    digitalWrite(RESET_PIN, HIGH);
}

void loop() {
    // Clock Fall
    digitalWrite(CLK_PIN, LOW);
    delayMicroseconds(5);

    // --- I/O Access ---
    if (digitalRead(IORQ_PIN) == LOW) {
        uint16_t port = getAddress() & 0xFF;
        if (digitalRead(WR_PIN) == LOW) {
            uint8_t data = getData();
            if (port == 0x80) {
                digitalWrite(WAIT_PIN, LOW); // Hold Z80
                
                display.write((char)data);
                display.display();
                
                if (display.getCursorY() >= 64) {
                    display.fillRect(0, 16, 128, 48, SSD1306_BLACK);
                    display.setCursor(0, 16);
                    display.display();
                }

                // Mimic the working version's delay rhythm
                for(int i = 0; i < 50; i++) {
                    digitalWrite(CLK_PIN, HIGH); delay(10);
                    digitalWrite(CLK_PIN, LOW);  delay(10);
                }

                digitalWrite(WAIT_PIN, HIGH); // Release Z80
            }
            // Ensure WR is released
            int timeout = 0;
            while(digitalRead(WR_PIN) == LOW && timeout < 1000) { pulseClock(); timeout++; }
        }
    }
    // --- Memory Access ---
    else if (digitalRead(MREQ_PIN) == LOW) {
        uint16_t addr = getAddress();
        if (digitalRead(RD_PIN) == LOW) {
            uint8_t data = virtual_memory[addr & 0x3FFF];
            setDataBusMode(OUTPUT);
            setData(data);
            while(digitalRead(RD_PIN) == LOW) { pulseClock(); }
            setDataBusMode(INPUT);
        } else if (digitalRead(WR_PIN) == LOW) {
            uint8_t data = getData();
            virtual_memory[addr & 0x3FFF] = data;
            while(digitalRead(WR_PIN) == LOW) { pulseClock(); }
        }
    }

    // Clock Rise
    digitalWrite(CLK_PIN, HIGH);
    delayMicroseconds(10);
}

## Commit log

2026-04-11 feat: initial public release
    [fritzing.fzz]
2026-04-11 Remove cad directory description from README
